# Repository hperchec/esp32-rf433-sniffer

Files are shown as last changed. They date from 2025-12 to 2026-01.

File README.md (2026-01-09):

# ESP32 RF433 Sniffer






## 🍵 Introduction

This is a DIY project to play and learn how 433MHz signals and related protocols work. For example,
you can read a signal from your remote to replicate or clone it...

It supports:

- "Old style" remote protocols (SC5262 / SC5272 / HX2262 / HX2272 / PT2262 / PT2272 / EV1527 / etc...) with the [RCSwitch](https://github.com/sui77/rc-switch) library
- "New style" remote protocols (HomeEasy, Chacon, KaKu, Intertechno, etc...) with the [NewRemoteSwitch](https://github.com/1technophile/NewRemoteSwitch) library

> ⚠️ **Important note**: the **MX-RM-5V** module used in this project is very cheap and extremely sensitive to noise and interference.
> Its range is very short, so it is not designed for complex or professional usage.

## Requirements

Hardware:

- ESP32 DevKitC (i'm using ESP32-WROOM-32)
- 433MHz receiver (MX-RM-5V module)
- 433MHz emitter (FS1000A module)
- RGB Led (common cathode)
- 330 Ohms resistor
- 2x 220 Ohms resistor
- 10k Ohms resistor
- 20k Ohms resistor
- wires

> ❗ **Important**: you will have to solder some parts

Software:

- Arduino IDE
- PuTTY [Optional]
- VSCode [Optional]

## Hardware

WIP

Here is the electronic schema below:

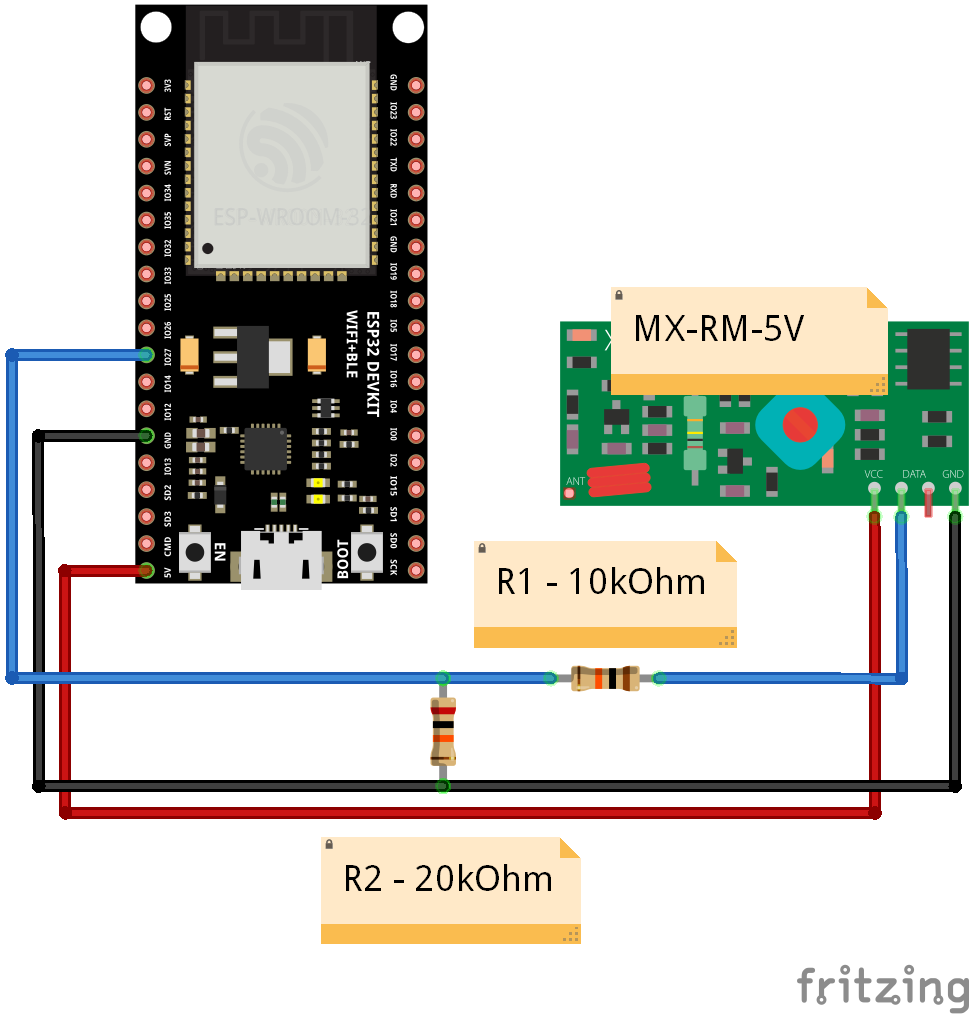
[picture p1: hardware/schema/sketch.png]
fritzing sketch


## Software

We will use the [Arduino IDE](https://docs.arduino.cc/software/ide/) (v2.3.6) to compile and upload program to the **ESP32 board**.

You can use other tool like [PlatformIO](https://platformio.org/), but this documentation **only covers Arduino IDE usage**.

### Arduino IDE setup

> 💡 **Note**: you can also follow [this tutorial](https://randomnerdtutorials.com/installing-the-esp32-board-in-arduino-ide-windows-instructions/) at *randomnerdtutorials.com*.

First, you need to install the **ESP32 board** in the IDE:

- go to **File** > **Preferences**
- enter the following URL into the **Additional Board Manager URLs** field:

  `https://espressif.github.io/arduino-esp32/package_esp32_index.json`

- then, open the Boards Manager by going to **Tools** > **Board** > **Boards Manager**
- search for `esp32` and press install button for the **"esp32 by Espressif Systems"**

Then, you need to install the [JLed](https://github.com/jandelgado/jled), [RCSwitch](https://github.com/sui77/rc-switch) and [NewRemoteSwitch](https://github.com/1technophile/NewRemoteSwitch) libraries:

- go to **Tools** > **Manage libraries**
- search for `JLed` and press install button for the **"JLed by Jan Delgado"**
- search for `rc-switch` and press install button for the **"rc-switch by sui77"**
- as the **NewRemoteSwitch** library requires manual installation, you can either:
  - include the library from `.zip` archive by following the [Arduino documentation instructions](https://docs.arduino.cc/software/ide-v1/tutorials/installing-libraries/#importing-a-zip-library)
  - or copy the `software/ESP32-RF433-Sniffer/libraries/NewRemoteSwitch` folder of this repository into the Arduino IDE sketchbook location folder (go to **File** > **Preferences** under **Sketchbook location** to know where it is located in your file system)

### Compile and upload

Plug your ESP32 to your computer via USB.

> ⚠️ You may need to install a [CP210x USB to UART Bridge VCP Driver](https://www.silabs.com/software-and-tools/usb-to-uart-bridge-vcp-drivers)

In the Arduino IDE:

- select the COM port in **Tools** > **Port:** menu
- select your board in **Tools** > **Board** menu (in my case it's the ESP32 Dev Module)
- go to **File** > **Open** and select the `software/ESP32-RF433-Sniffer/ESP32-RF433-Sniffer.ino` file

You can now upload the program to your ESP32.

> 💡 **Note**: you may need to press the "BOOT" button on your ESP32 board when connecting to start uploading

Once the program is uploaded, you can start to play with your sniffer! 😎. See below how to use it.

## Usage

Your sniffer is now ready to be used. You will need a tool like [PuTTY](https://putty.org/index.html) installed on your computer to
communicate with.

Once your sniffer is plugged to your computer, open PuTTY and set the following values in the **Session** section:

- Serial line: `COMX` (replace `X` by your number)
- Speed: `115200`
- Connection type : "Serial"

Then, in the **Terminal** section:

- enable "Implicit LF in every CR"
- Local echo must be "Force on"
- Local line editing must be "Force on"

> 💡 **Note**: you can save the session to re-use later.

Enjoy! 😉

## 🤝 Contribute

You would like to contribute to this project? You are welcome!

Feel free to contact me, open a PR or issue...

## 👑 Author

Made with ❤ by [Hervé Perchec](https://github.com/hperchec)

## ⚖️ License

[AGPL-3.0](./LICENSE)

## 🏆 Credits

Thanks to:

- [Jan Delgado](https://github.com/jandelgado) for the [JLed](https://github.com/jandelgado/jled) library (v4.15.0)
- [Suat Özgür](https://github.com/sui77) for the [RCSwitch](https://github.com/sui77/rc-switch) library (v2.6.4)
- [Florian Robert](https://github.com/1technophile) & [Randy Simons](http://randysimons.nl/) for the [NewRemoteSwitch](https://github.com/1technophile/NewRemoteSwitch) library (v1.2.0)

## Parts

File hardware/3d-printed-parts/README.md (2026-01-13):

# Parts

- [Bottom](./000-bottom/) (x1)
- [Top](./001-top/) (x1)
- [ESP32 support](./002-esp32-support/) (x1)
- [FS1000A support](./003-fs1000a-support/) (x1)
- [Led support](./004-led-support/) (x1)
- [MX-RM-5V support](./005-mx-rm-5v-support/) (x1)
- [Lens](./006-lens/) (x1)

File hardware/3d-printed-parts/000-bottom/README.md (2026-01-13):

# 000-bottom (ESP32 RF433 Sniffer - Bottom)

## Informations

**Version**: `1.0`

**Reference**: `000-bottom`

**Name**: `Bottom`

## Printing details

|Infill |Supports |Rafts |Resolution |Filament |
|- |- |- |- |- |
|17% |Doesn't matter |Doesn't matter |0.20mm |Doesn't matter  |

## Images

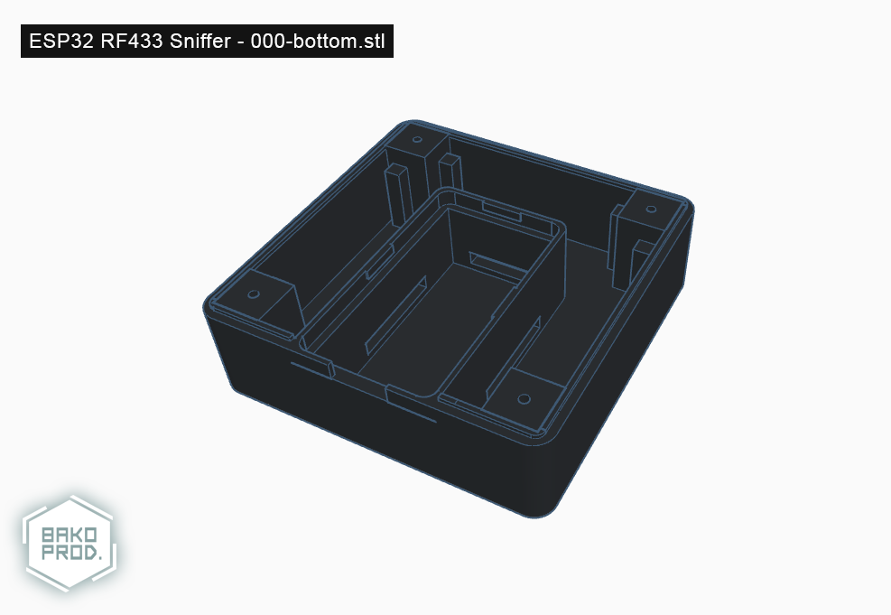
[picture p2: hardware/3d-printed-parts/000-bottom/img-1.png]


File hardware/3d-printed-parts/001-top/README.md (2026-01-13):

# 001-top (ESP32 RF433 Sniffer - Top)

## Informations

**Version**: `1.0`

**Reference**: `001-top`

**Name**: `Top`

## Printing details

|Infill |Supports |Rafts |Resolution |Filament |
|- |- |- |- |- |
|17% |Doesn't matter |Doesn't matter |0.20mm |Doesn't matter  |

## Images

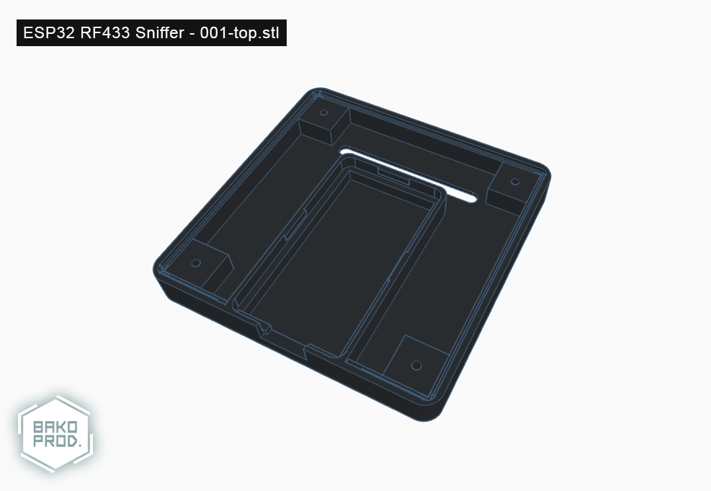
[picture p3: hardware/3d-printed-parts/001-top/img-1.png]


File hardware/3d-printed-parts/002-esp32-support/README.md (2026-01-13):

# 002-esp32-support (ESP32 RF433 Sniffer - ESP32 support)

## Informations

**Version**: `1.0`

**Reference**: `002-esp32-support`

**Name**: `ESP32 support`

## Printing details

|Infill |Supports |Rafts |Resolution |Filament |
|- |- |- |- |- |
|17% |Doesn't matter |Doesn't matter |0.20mm |Doesn't matter  |

## Images

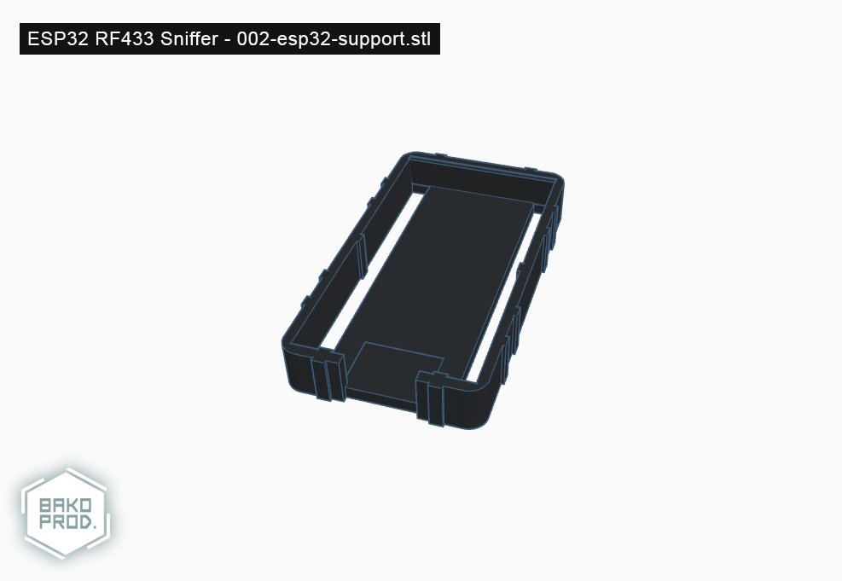
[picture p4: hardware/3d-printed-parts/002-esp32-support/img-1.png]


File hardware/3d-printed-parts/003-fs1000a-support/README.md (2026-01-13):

# 003-fs1000a-support (ESP32 RF433 Sniffer - FS1000A support)

## Informations

**Version**: `1.0`

**Reference**: `003-fs1000a-support`

**Name**: `FS1000A support`

## Printing details

|Infill |Supports |Rafts |Resolution |Filament |
|- |- |- |- |- |
|17% |Doesn't matter |Doesn't matter |0.20mm |Doesn't matter  |

## Images

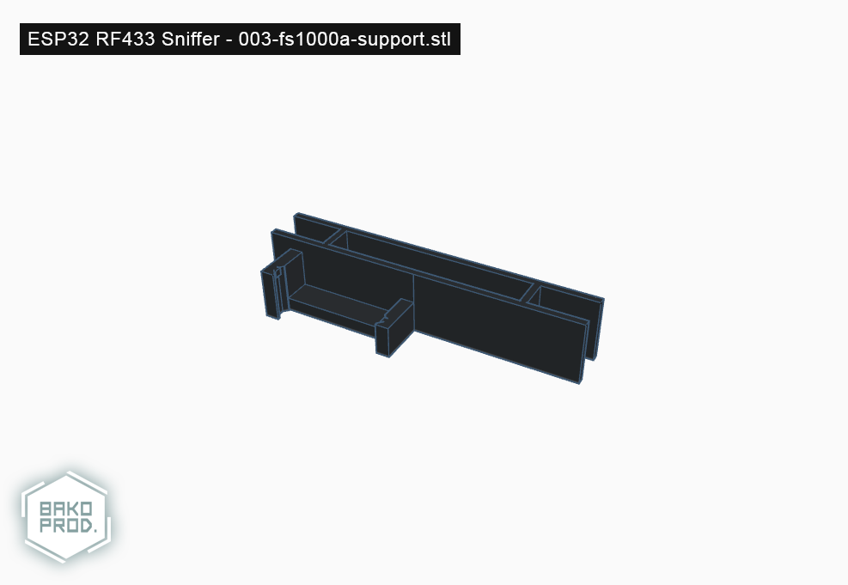
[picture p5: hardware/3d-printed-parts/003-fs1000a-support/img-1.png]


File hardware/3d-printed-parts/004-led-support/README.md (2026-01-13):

# 004-led-support (ESP32 RF433 Sniffer - Led support)

## Informations

**Version**: `1.0`

**Reference**: `004-led-support`

**Name**: `Led support`

## Printing details

|Infill |Supports |Rafts |Resolution |Filament |
|- |- |- |- |- |
|17% |Doesn't matter |Doesn't matter |0.20mm |Doesn't matter  |

## Images

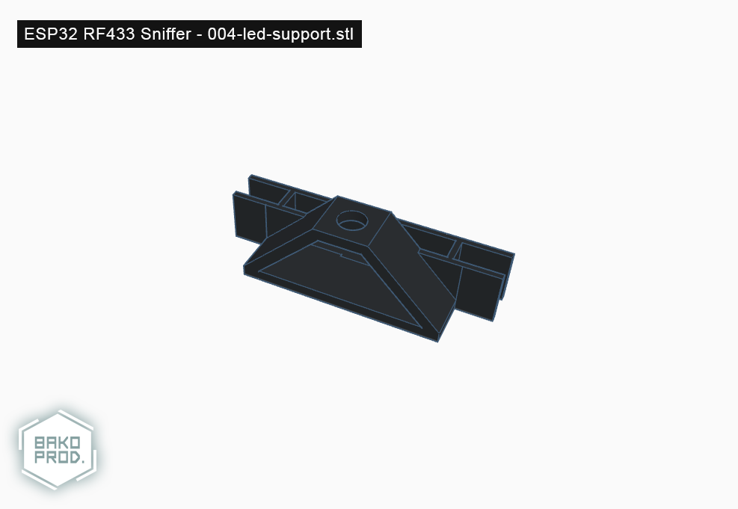
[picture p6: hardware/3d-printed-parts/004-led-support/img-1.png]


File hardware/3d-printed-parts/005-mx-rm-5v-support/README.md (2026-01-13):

# 005-mx-rm-5v-support (ESP32 RF433 Sniffer - MX-RM-5V support)

## Informations

**Version**: `1.0`

**Reference**: `005-mx-rm-5v-support`

**Name**: `MX-RM-5V support`

## Printing details

|Infill |Supports |Rafts |Resolution |Filament |
|- |- |- |- |- |
|17% |Doesn't matter |Doesn't matter |0.20mm |Doesn't matter  |

## Images

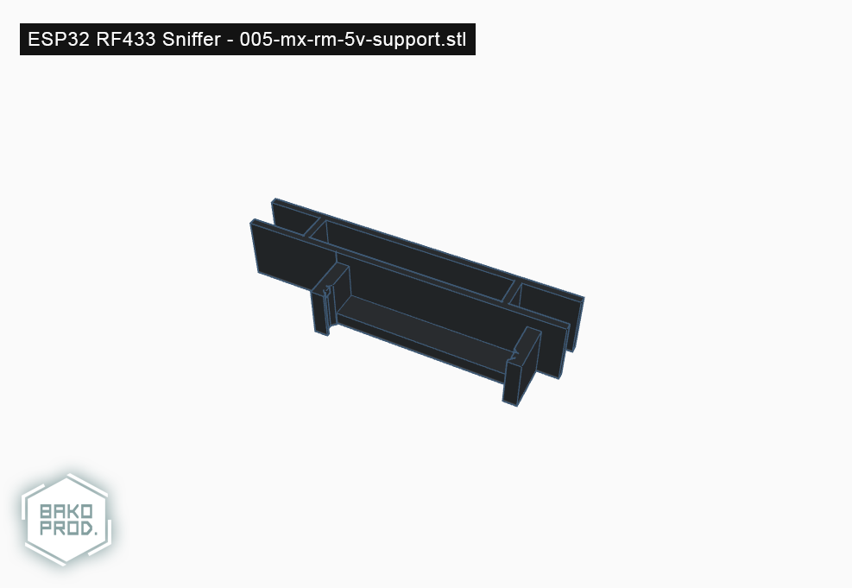
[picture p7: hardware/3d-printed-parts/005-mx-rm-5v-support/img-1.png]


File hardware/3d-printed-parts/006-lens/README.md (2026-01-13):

# 006-lens (ESP32 RF433 Sniffer - Lens)

## Informations

**Version**: `1.0`

**Reference**: `006-lens`

**Name**: `Lens`

## Printing details

|Infill |Supports |Rafts |Resolution |Filament |
|- |- |- |- |- |
|100% |Doesn't matter |Doesn't matter |0.20mm |Transparent |

## Images

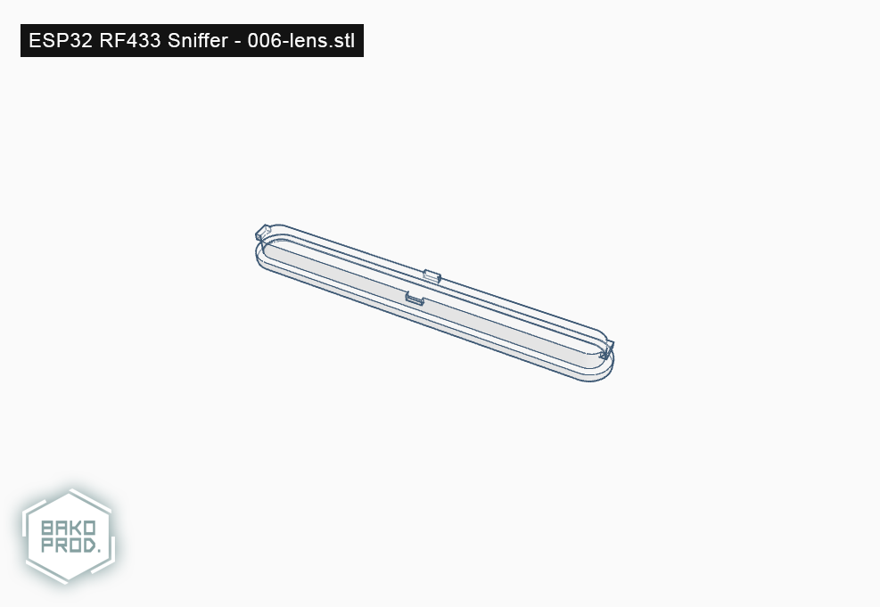
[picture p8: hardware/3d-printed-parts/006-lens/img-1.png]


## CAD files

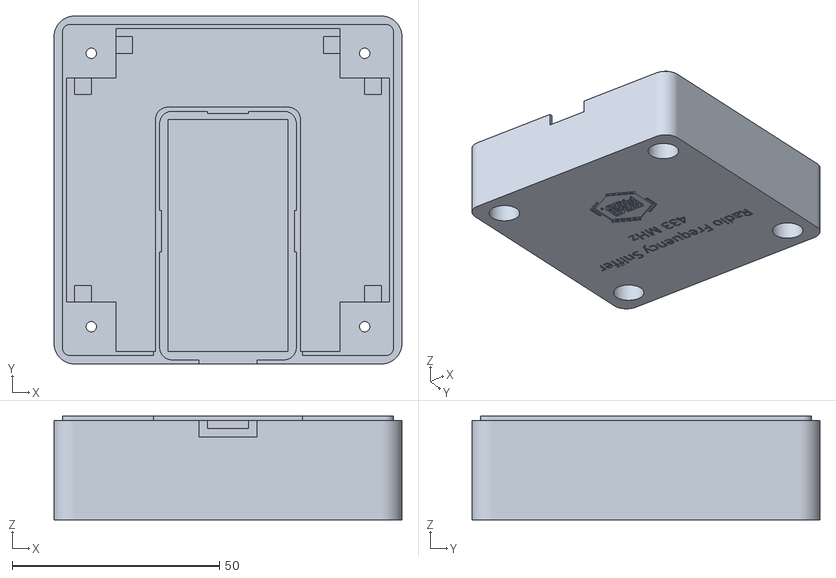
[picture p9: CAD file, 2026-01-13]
hardware/3d-printed-parts/000-bottom/000-bottom.stl
84.0 x 84.0 x 25.0

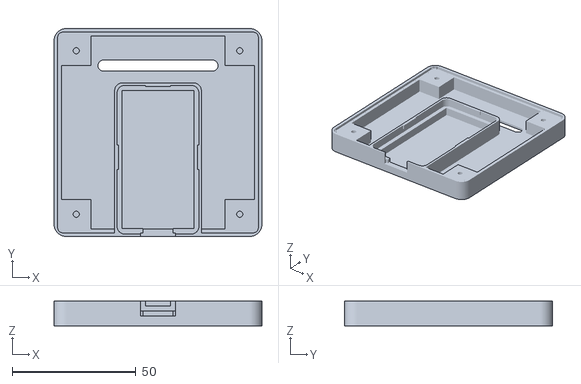
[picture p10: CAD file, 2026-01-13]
hardware/3d-printed-parts/001-top/001-top.stl
84.0 x 84.0 x 10.0

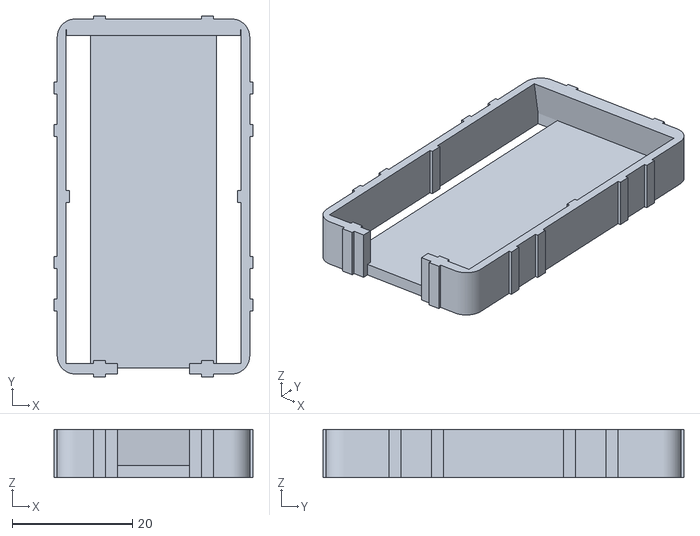
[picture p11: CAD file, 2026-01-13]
hardware/3d-printed-parts/002-esp32-support/002-esp32-support.stl
33.0 x 60.0 x 8.00

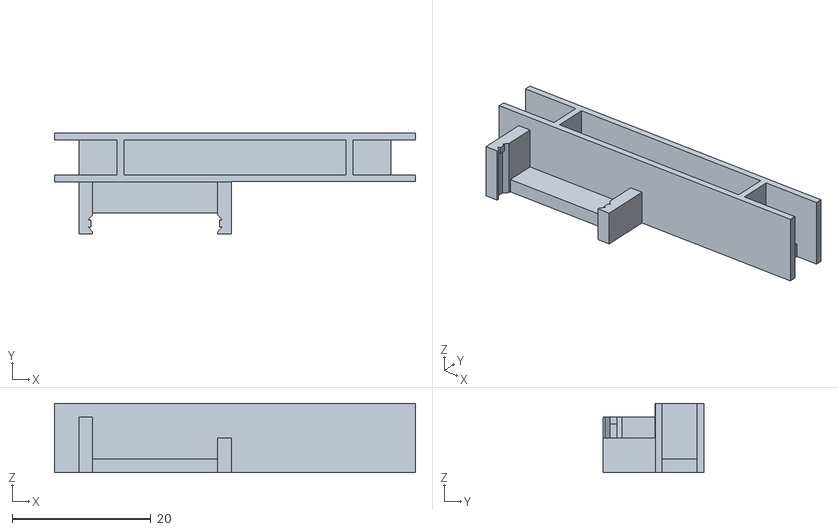
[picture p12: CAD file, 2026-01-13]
hardware/3d-printed-parts/003-fs1000a-support/003-fs1000a-support.stl
52.0 x 14.5 x 10.0

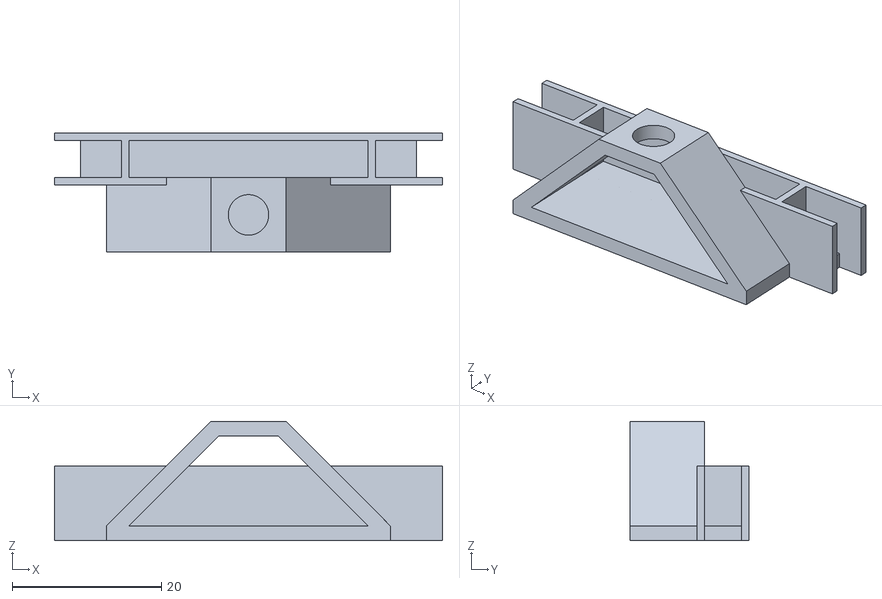
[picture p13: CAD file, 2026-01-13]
hardware/3d-printed-parts/004-led-support/004-led-support.stl
52.0 x 16.0 x 16.0

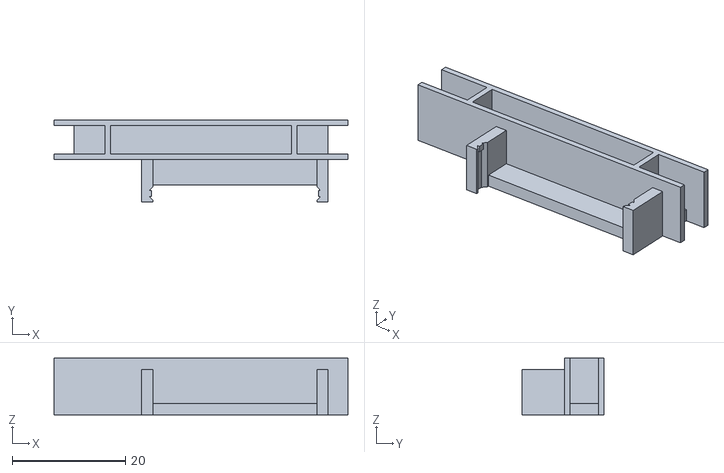
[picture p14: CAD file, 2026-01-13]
hardware/3d-printed-parts/005-mx-rm-5v-support/005-mx-rm-5v-support.stl
52.0 x 14.5 x 10.0

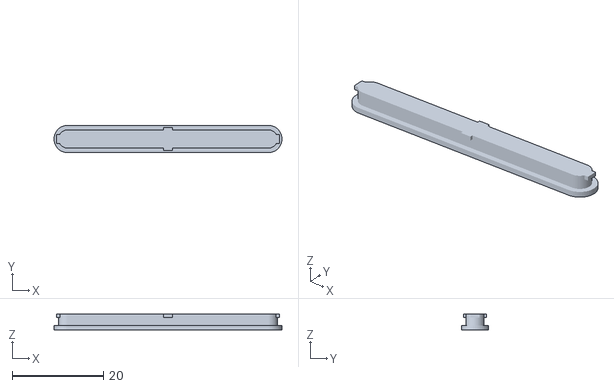
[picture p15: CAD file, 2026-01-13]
hardware/3d-printed-parts/006-lens/006-lens.stl
50.0 x 6.00 x 3.50

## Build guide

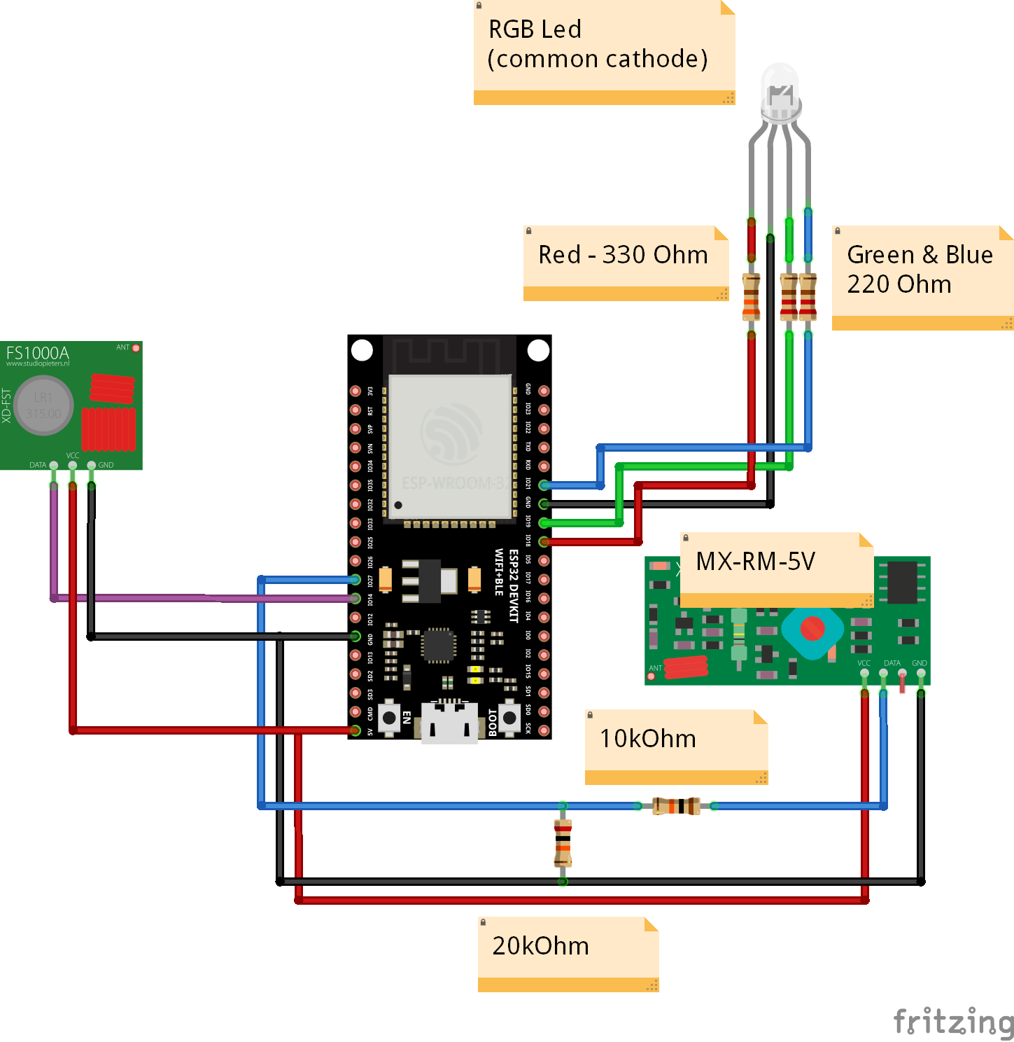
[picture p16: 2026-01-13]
hardware/wiring-diagram/sketch.png

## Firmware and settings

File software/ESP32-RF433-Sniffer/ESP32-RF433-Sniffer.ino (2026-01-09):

/**
 * ESP32-RF433-Sniffer
 *
 * @author Hervé Perchec (https://github.com/hperchec)
 *
 * Copyright (c) 2025 Hervé Perchec. All right reserved.
 * License: GNU AFFERO GENERAL PUBLIC LICENSE (see LICENSE file)
 */

#include <RCSwitch.h>
#include <NewRemoteReceiver.h>
#include <NewRemoteTransmitter.h>
#include "Config.h"
#include "Utils.h"
#include "Data.h"
#include "CLI.h"
#include "Led.h"

// Create a RCSwitch instance
RCSwitch rcSwitch = RCSwitch();

// Create instance type 1 data
Type1Data t1Data;
// Create instance type 2 data
Type2Data t2Data;
// Flag for type 2 data availability
bool type2DataAvailable = false;

// Init RGB led
Led rgbLed = Led(new RGBCC(RGB_LED_RED_PIN, RGB_LED_GREEN_PIN, RGB_LED_BLUE_PIN));

// Init transmitter repeater
Repeater transmitRepeater = Repeater();

/**
 * Setup function
 * See https://docs.arduino.cc/language-reference/en/structure/sketch/setup/
 */
void setup () {
  // Set baudrate for serial connection
  Serial.begin(SERIAL_BAUDRATE);
  // Reduce serial timeout for Serial.readStringUntil method (default is 1000)
  Serial.setTimeout(100);
  // Arbitrary delay for PuTTY like tools
  delay(1000);

  CLI::printHeader();
  CLI::printMenu();
  CLI::printPromptPrefix();

  // Init led state
  refreshLedState();
}

/**
 * Loop function
 * See https://docs.arduino.cc/language-reference/en/structure/sketch/loop/
 */
void loop () {
  // Always update led and repeater
  rgbLed.update();
  transmitRepeater.update();

  // Try to read serial command
  String input = readSerialCommand();

  // If transmitter is currently sending signals
  if (transmitRepeater.isRunning()) {
    if (input.length() > 0 && CLI::handleQuitCommand(input)) {
      transmitRepeater.stop();
    }
  } else {
    // Handle user command
    if (input.length() > 0) {
      CLI::handleSerialCommands(input);
    }

    // Type 1 data available
    if (CLI::currentType == OLD_STYLE && rcSwitch.available()) {
      rgbLed.receivingState();
      rgbLed.setTimeout([]() {
        refreshLedState();
      }, 400 /* duration of receivingState */);
      // Get data
      t1Data = createData(
        rcSwitch.getReceivedValue(), // decimal
        rcSwitch.getReceivedProtocol(), // protocol
        rcSwitch.getReceivedDelay(), // delay
        rcSwitch.getReceivedBitlength(), // length
        rcSwitch.getReceivedRawdata() // raw
      );
      // Show data
      Serial.println(F("\r\n------------ DECODED SIGNAL ------------"));
      logData(t1Data);
      Serial.println(F("----------------------------------------"));

      rcSwitch.resetAvailable();
      // Always clear data
      t1Data.clear();

      CLI::printPromptPrefix();
    }

    // Type 2 data available
    if (CLI::currentType == NEW_STYLE && type2DataAvailable) {
      rgbLed.receivingState();
      rgbLed.setTimeout([]() {
        refreshLedState();
      }, 400 /* duration of receivingState */);
      // Show data
      Serial.println(F("\r\n------------ DECODED SIGNAL ------------"));
      logData(t2Data);
      Serial.println(F("----------------------------------------"));

      type2DataAvailable = false;
      // Always clear data
      t2Data.clear();

      CLI::printPromptPrefix();
    }
  }

}

/**
 * Apply the specific led state based on current mode
 */
void refreshLedState () {
  if (CLI::currentMode == NONE_MODE) {
    rgbLed.mainMenuState();
  } else if (CLI::currentMode == RECEIVE_MODE) {
    if (CLI::currentType == NONE_TYPE) {
      rgbLed.receiveMenuState();
    } else {
      rgbLed.readyToReceiveState();
    }
  } else {
    if (CLI::currentType == NONE_TYPE) {
      rgbLed.transmitMenuState();
    } else {
      rgbLed.readyToTransmitState();
    }
  }
  rgbLed.update();
}

void CLI::onHelp () {
  printMenu();
  printPromptPrefix();
}

void CLI::onQuit () {
  stopAndBack();
  printMenu();
  printPromptPrefix();
}

void CLI::onModeChosen () {
  refreshLedState();
}

void CLI::onTypeChosen () {
  if (currentMode == RECEIVE_MODE) {
    startReceiveMode();
  } else {
    startTransmitMode();
  }
}

void CLI::onSend (String input) {
  if (currentType == OLD_STYLE) {
    Type1Data data;
    try {
      data = parseType1SendCommand(input);
    } catch (String error) {
      Serial.println(F("ERROR: unable to parse the given command. Type ? to show help."));
    }
    Serial.println(F("----------------------------------------"));
    logData(data);
    Serial.println(F("----------------------------------------"));

    Serial.print("Sending");
    transmitRepeater.start([data](unsigned long count) {
      Serial.print(".");
      rgbLed.sendingState();
      rgbLed.setTimeout([data]() {
        refreshLedState();
        unsigned long timeStart = millis();
        // This function is "blocking": it uses delay() under the hood
        sendType1Data(data); // ≃ 370 ms but consider 1400 ms to match same interval as Type2Data sending
      }, 400 /* duration of sendingState */);
    }, 10, 2000); // Every 1400 + 400 + 200 (safety margin) ms
    transmitRepeater.onStop([](unsigned long count) {
      Serial.print("Stopped. Signal has been sent "); Serial.print(count); Serial.println(" times");
      refreshLedState();
      CLI::printPromptPrefix();
    });
  } else {
    Type2Data data;
    try {
      data = parseType2SendCommand(input);
    } catch (String error) {
      Serial.println(F("ERROR: unable to parse the given command. Type ? to show help."));
    }
    Serial.println(F("----------------------------------------"));
    logData(data);
    Serial.println(F("----------------------------------------"));

    Serial.print("Sending");
    transmitRepeater.start([data](unsigned long count) {
      Serial.print(".");
      rgbLed.sendingState();
      rgbLed.setTimeout([data]() {
        refreshLedState();
        // This function is "blocking": it uses delay() under the hood
        sendType2Data(data); // ≃ 1400 ms
      }, 400 /* duration of sendingState */);
    }, 10, 2000); // Every 1400 + 400 + 200 (safety margin) ms
    transmitRepeater.onStop([](unsigned long count) {
      Serial.print("Stopped. Signal has been sent "); Serial.print(count); Serial.println(" times");
      refreshLedState();
      CLI::printPromptPrefix();
    });
  }
}

/**
 * Start the receiver based on currentType
 */
void startReceiveMode () {
  if (CLI::currentType == OLD_STYLE) {
    rcSwitch.enableReceive(digitalPinToInterrupt(RX_PIN));
  } else {
    NewRemoteReceiver::init(RX_PIN, 2, nrsInitCallback);
  }
  refreshLedState();
  Serial.println(F("Listening..."));
}

/**
 * Start the transmitter based on currentType
 */
void startTransmitMode () {
  if (CLI::currentType == OLD_STYLE) {
    rcSwitch.enableTransmit(digitalPinToInterrupt(TX_PIN));
  } else {
    // No need to setup NewRemoteSwitch...
    // See sendType2Data function below
  }
  refreshLedState();
  Serial.println(F("Waiting for send command..."));
}

/**
 * Stop current receiver or transmitter and back to previous menu
 */
void stopAndBack () {
  switch (CLI::currentMode) {
    case NONE_MODE:
      // Nothing...
      break;
    case RECEIVE_MODE:
      // No type selected? back to main menu
      if (CLI::currentType == NONE_TYPE) {
        CLI::currentMode = NONE_MODE;
      } else {
        if (CLI::currentType == OLD_STYLE) {
          rcSwitch.disableReceive();
        } else if (CLI::currentType == NEW_STYLE) {
          NewRemoteReceiver::deinit();
        }
        Serial.println(F("Receiver stopped"));
        CLI::currentType = NONE_TYPE;
      }
      refreshLedState();
      break;
    case TRANSMIT_MODE:
      // No type selected? back to main menu
      if (CLI::currentType == NONE_TYPE) {
        CLI::currentMode = NONE_MODE;
      } else {
        // "Old" style? disable transmit
        if (CLI::currentType == OLD_STYLE) {
          rcSwitch.disableTransmit();
        }
        // Reset current type only if transmitRepeater is not running
        if (!transmitRepeater.isRunning()) {
          CLI::currentType = NONE_TYPE;
        }
      }
      refreshLedState();
      break;
  }
}

/**
 * The callback function to pass to NewRemoteSwitch::init method.
 * Called every time a signal is decoded by NewRemoteSwitch library
 */
void nrsInitCallback (unsigned int period, unsigned long address, unsigned long groupBit, unsigned long unit, unsigned long switchType, boolean dimLevelPresent, byte dimLevel) {
  t2Data = createData(
    period,
    address,
    groupBit,
    unit,
    switchType,
    dimLevelPresent,
    dimLevel
  );
  type2DataAvailable = true;
}

/**
 * Create and return a Type1Data object
 */
Type1Data createData (unsigned long decimal, unsigned int protocol, unsigned int delay, unsigned int length, unsigned int* raw) {
  Type1Data data;
  data.decimal = decimal;
  data.protocol = protocol;
  data.delay = delay;
  data.length = length;
  data.raw = raw;
  data.bin = dec2binWzerofill(decimal, length);
  data.triState = bin2tristate(data.bin);
  return data;
}

/**
 * Create and return a Type2Data object
 */
Type2Data createData (unsigned int period, unsigned long address, unsigned long groupBit, unsigned long unit, unsigned long switchType, boolean dimLevelPresent, byte dimLevel) {
  Type2Data data;
  data.period = period;
  data.address = address;
  data.groupBit = groupBit;
  data.unit = unit;
  switch (switchType) {
    case Type2Data::off:
      data.switchType = Type2Data::off;
      break;
    case Type2Data::on:
      data.switchType = Type2Data::on;
      break;
    case Type2Data::dim:
      data.switchType = Type2Data::dim;
      break;
  }
  data.dimLevelPresent = dimLevelPresent;
  if (dimLevelPresent) {
    data.dimLevel = dimLevel;
  } else {
    data.dimLevel = 0;
  }
  return data;
}

/**
 * Command syntax: <decimal> <protocol> <delay> <length>
 * Example: 5592332 1 350 24
 */
Type1Data parseType1SendCommand (String input) {
  String tokens[4] = { "", "", "", "" };
  int i = 0;
  while (input.length() > 0 && i < 4) {
    int index = input.indexOf(' ');
    if (index == -1) {
      tokens[i++] = input;
      break;
    } else {
      tokens[i++] = input.substring(0, index);
      input = input.substring(index + 1);
    }
  }

  Type1Data data = createData(
    strtoul(tokens[0].c_str(), NULL, 10), // decimal
    tokens[1].toInt(), // protocol
    tokens[2].toInt(), // delay
    tokens[3].toInt(), // length
    nullptr // raw
  );

  return data;
}

/**
 * Send (type 1) data with rc-switch
 */
void sendType1Data (Type1Data data) {
  // Configure transmitter
  rcSwitch.setProtocol(data.protocol);
  rcSwitch.setPulseLength(data.delay);
  // Send signals
  rcSwitch.send(data.decimal, data.length);
}

/**
 * <address> <period> <group> <unit> <state> [<dimLevel>]
 */
Type2Data parseType2SendCommand (String input) {
  String tokens[6] = { "", "", "", "", "", "" };
  int i = 0;
  // Split the input into substrings
  while (input.length() > 0) {
    int index = input.indexOf(' ');
    if (index == -1) { // No space found
      tokens[i++] = input;
      break;
    } else {
      tokens[i++] = input.substring(0, index);
      input = input.substring(index+1);
    }
  }

  bool dimLevelPresent = (tokens[5] && tokens[5].length() > 0);

  Type2Data data = createData(
    tokens[1].toInt(), // period
    tokens[0].toInt(), // address
    tokens[2].toInt(), // groupbit
    tokens[3].toInt(), // unit
    tokens[4].toInt(), // switchType
    dimLevelPresent,
    dimLevelPresent ? tokens[5].toInt() : 0 // dimLevel
  );

  return data;
}

/**
 * Send (type 2) data with NewRemoteTransmitter
 */
void sendType2Data (Type2Data data) {
  // Create a new transmitter with the received address and period, use a digital pin as output pin
  NewRemoteTransmitter transmitter(data.address, TX_PIN, data.period);

  if (data.switchType == Type2Data::dim ||
    (data.switchType == Type2Data::on && data.dimLevelPresent)) {
    // Dimmer signal received
    if (data.groupBit) {
      transmitter.sendGroupDim(data.dimLevel);
    } else {
      transmitter.sendDim(data.unit, data.dimLevel);
    }
  } else {
    // On/Off signal
    bool isOn = data.switchType == Type2Data::on;
    if (data.groupBit) {
      // Send to the group
      transmitter.sendGroup(isOn);
    } else {
      // Send to a single unit
      transmitter.sendUnit(data.unit, isOn);
    }
  }
}

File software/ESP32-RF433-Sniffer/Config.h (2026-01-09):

/**
 * ESP32-RF433-Sniffer
 *
 * @author Hervé Perchec (https://github.com/hperchec)
 *
 * Copyright (c) 2025 Hervé Perchec. All right reserved.
 * License: GNU AFFERO GENERAL PUBLIC LICENSE (see LICENSE file)
 */

#ifndef CONFIG_H
#define CONFIG_H

#include "RGBCC.h"

// You can adapt these values to fill your needs

// By default, it uses the GPIO27 to receive signals and GPIO14 to emit
// You can adapt these values to fill your needs
const int RX_PIN = 27;
const int TX_PIN = 14;

// Define the serial connection baud rate
const int SERIAL_BAUDRATE = 115200;

// R: GPIO18, G: GPIO19, B: GPIO21
const int RGB_LED_RED_PIN = 18;
const int RGB_LED_GREEN_PIN = 19;
const int RGB_LED_BLUE_PIN = 21;

// Custom led colors: { R, G, B }
const RGBColor PURPLE_COLOR = { 150, 0, 255 };
const RGBColor TURQUOISE_COLOR = { 0, 100, 200 };
const RGBColor GREEN_COLOR = { 50, 255, 0 };

#endif

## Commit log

2025-12-22 chore: add fritzing sketch
    [sketch.fzz]
2026-01-13 chore: add 3d printed parts
    [000-bottom.stl, 001-top.stl, 002-esp32-support.stl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]
2026-01-13 chore: update wiring diagram
    [sketch.fzz]
